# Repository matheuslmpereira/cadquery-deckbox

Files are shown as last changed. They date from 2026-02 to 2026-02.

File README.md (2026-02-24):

# cadquery-deckbox

## Environment

- Python: `3.11.14` (required for this setup)
- CadQuery: `2.6.1`
- OCP Viewer package: `ocp_vscode 3.0.1`
- Virtualenv interpreter:
  - `/Users/matheuslmpereira/Workspace/cadquery-deckbox/.venv/bin/python`

## Setup

```bash
cd /Users/matheuslmpereira/Workspace/cadquery-deckbox
/opt/homebrew/bin/python3.11 -m venv .venv
source .venv/bin/activate
pip install -r requirements.txt
```

## Run

```bash
source .venv/bin/activate
python build_box.py
python build_box.py --model commander_100
python build_box.py --model constructed_60_15
python build_box.py --model uno_36
python build_box.py --model color_addicted_40
python build_box.py --model commander_100 --no-viewer-output
```

- Sem `--model`, o script abre um seletor interativo no terminal.
- Por padrao, o script exporta um arquivo `.step` da montagem para CAD viewer.

## Verify environment

```bash
which python
python --version
python -m pip show cadquery ocp_vscode | rg "^Name:|^Version:"
```

Expected:

- `which python` -> `/Users/matheuslmpereira/Workspace/cadquery-deckbox/.venv/bin/python`
- `python --version` -> `Python 3.11.14`

## Notes

- Running with `/opt/homebrew/bin/python3 build_box.py` without activating `.venv` will fail with `ModuleNotFoundError: cadquery`.
- STL files are exported with model slug + version in the filename.
- In VSCode, select interpreter:
  - `Python: Select Interpreter` -> `/Users/matheuslmpereira/Workspace/cadquery-deckbox/.venv/bin/python`

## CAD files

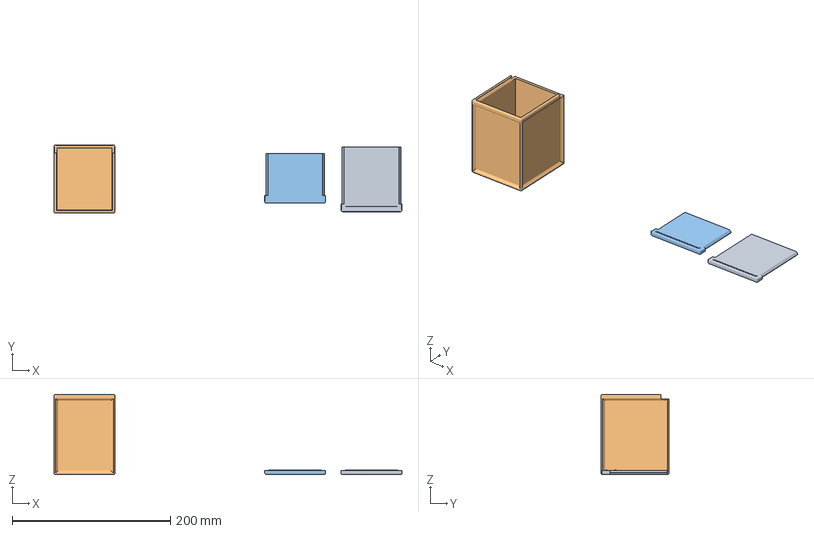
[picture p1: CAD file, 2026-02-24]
commander_deck_box_rainbow.3mf
439.7 x 86.0 x 101.3 mm
commander_deck_box_commander_100_lid_hex_v3.1.5.stl
commander_deck_box_commander_100_body_v3.1.5.stl
commander_deck_box_constructed_60_15_lid_hex_v3.1.5.stl

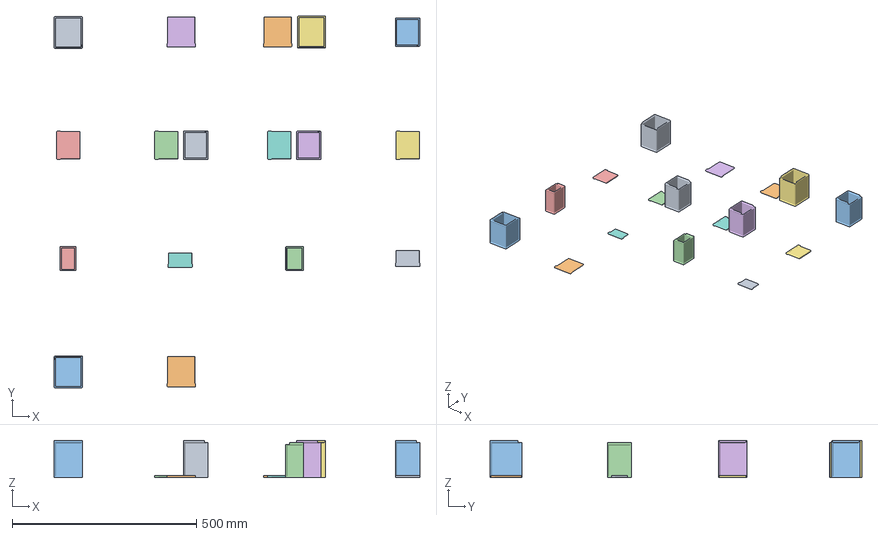
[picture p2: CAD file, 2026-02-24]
commander_deck_box_body_v3.0.10_valt.3mf
992.7 x 1007.9 x 101.3 mm
commander_deck_box_body_v3.0.8.stl x 2
commander_deck_box_commander_100_lid_hex_v3.1.5.stl
commander_deck_box_commander_100_body_v3.1.5.stl
commander_deck_box_color_addicted_40_body_v3.1.5.stl
commander_deck_box_uno_36_body_v3.1.5.stl
commander_deck_box_constructed_60_15_body_v3.1.1.stl x 3
commander_deck_box_constructed_60_15_lid_hex_v3.1.2.stl x 2
commander_deck_box_lid_hex_v3.0.10.stl x 2
commander_deck_box_constructed_60_15_lid_hex_v3.1.1.stl x 2
commander_deck_box_uno_36_lid_hex_v3.1.5.stl
commander_deck_box_color_addicted_40_lid_hex_v3.1.5.stl

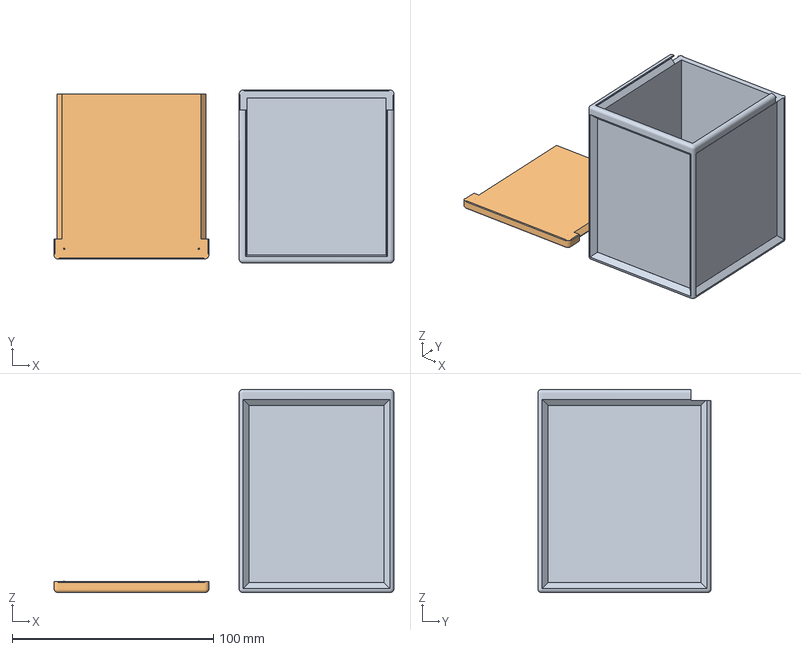
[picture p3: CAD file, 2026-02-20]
commander_deck_box_body_v3.0.6.3mf
169.0 x 86.0 x 101.1 mm
commander_deck_box_body_v3.0.6.stl
commander_deck_box_lid_hex_v3.0.6.stl

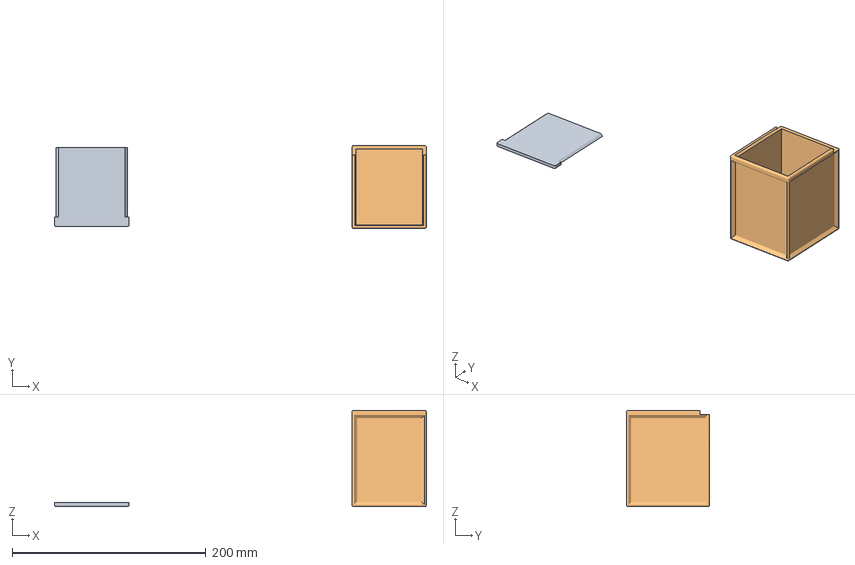
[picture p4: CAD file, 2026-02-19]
commander_deck_box_body_v3.0.5_gastadeira.3mf
384.2 x 86.0 x 99.6 mm
commander_deck_box_lid_hex_v3.0.5.stl
commander_deck_box_body_v3.0.5.stl

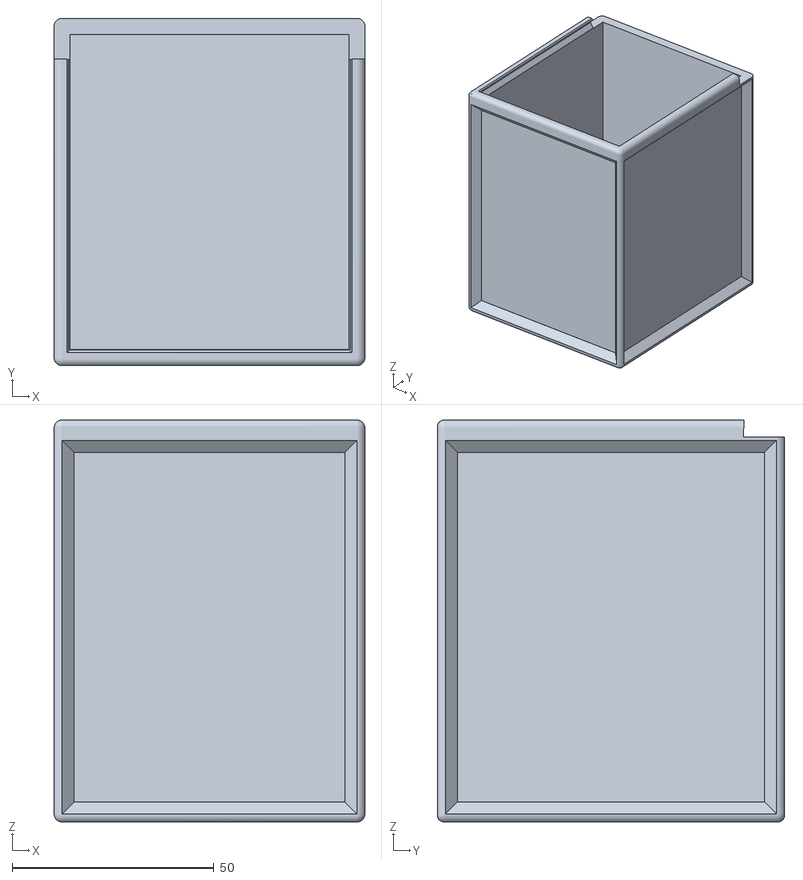
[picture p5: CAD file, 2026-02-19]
commander_deck_box_body_v3.0.0.stl
77.0 x 86.0 x 99.6

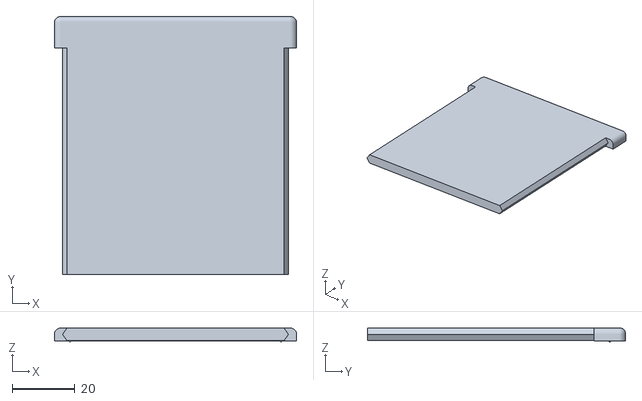
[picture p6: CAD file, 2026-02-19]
commander_deck_box_lid_hex_v3.0.0.stl
77.0 x 82.0 x 4.41

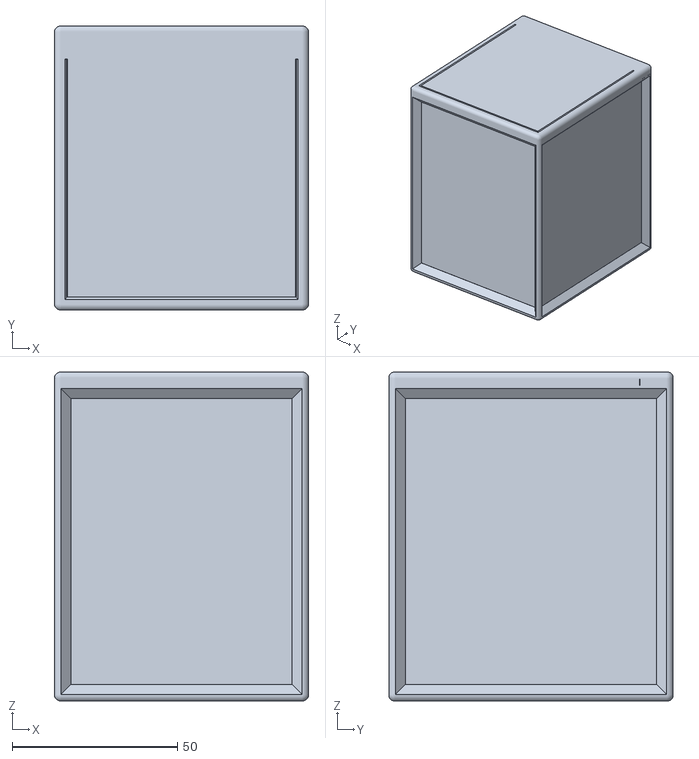
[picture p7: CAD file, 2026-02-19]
commander_deck_box_hex_v3.0.0.stl
77.0 x 86.0 x 99.6

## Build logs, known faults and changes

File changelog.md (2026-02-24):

# Model Changelog

- `v3.1.5`: Ajusta perfis UNO (`uno_36` e `color_addicted_40`) para fit de largura/altura com folga total de 2 mm.
- `v3.1.4`: Adiciona novos perfis de caixa com formato de carta UNO: `uno_36` (36 mm de profundidade interna) e `color_addicted_40` (40 mm de profundidade interna).
- `v3.1.3`: Adiciona no `build_box.py` export opcional de arquivo STEP da montagem para visualizacao em CAD viewer.
- `v3.1.2`: Adiciona segundo nivel na trava retangular de fechamento, com margem de 0.5 mm em relacao ao primeiro retangulo.
- `v3.1.1`: Adiciona seletor interativo de modelo no `build_box.py` quando `--model` nao e informado (escolha por numero ou slug no terminal).
- `v3.1.0`: Refatora execucao para `build_box.py` com selecao de perfil de caixa (`commander_100` e `constructed_60_15`), separa `main` da modelagem, e passa a incluir o slug do modelo no nome dos STLs exportados.
- `v3.0.10`: Desloca a trava retangular de fechamento em -1.0 mm no eixo Y.
- `v3.0.9`: Aumenta a altura da trava retangular de fechamento da tampa para 0.3 mm.
- `v3.0.8`: Substitui bolinhas de fechamento por trava retangular na tampa (profundidade 3.0 mm, altura 0.2 mm), mantendo as extremidades alinhadas com as posicoes laterais anteriores das bolinhas.
- `v3.0.7`: Aumenta a espessura do fundo da caixa para 0.84 mm (0.28 x 3 camadas).
- `v3.0.6`: Refina encaixe e manutencao: centraliza relief em `fit_relief_mm`, corrige alivio do sulco para eixos X/Z, adiciona crop do insert frontal no eixo Z, isola fusao em `fuseShapes` e alinha fluxo final para assembly sem recorte extra do corpo.
- `v3.0.5`: Ajustes de organização de projeto e minor fixis para a tampa
- `v3.0.4`: Aumenta lado do hexagono da tampa (hex_tip_offset_mm) para ampliar o corte de encaixe na caixa.
- `v3.0.3`: Remove groove_cut_depth_mm e sua logica; profundidade do sulco passa a depender apenas da geometria da tampa.
- `v3.0.2`: Remove duplicidade no corte do sulco; groove_cut_depth_mm agora estende a base do cutter de forma continua.
- `v3.0.1`: Aumenta um pouco a profundidade do sulco da tampa e passa a aplicar groove_cut_depth_mm no corte.
- `v3.0.0`: Versao estavel e imprimivel validada em PETG.
- `v2.0.25`: Reduz tamanho dos detentes em 20%.
- `v2.0.24`: Move detentes da tampa para a face inferior usando modo z_inner.
- `v2.0.23`: Corrige z_outer/z_inner para aplicar detentes em faces Z reais da tampa (nao mais alias de Y).
- `v2.0.22`: Padroniza nomenclatura de detentes para face Z (z_outer/z_inner), mantendo compatibilidade com y_outer/y_inner.
- `v2.0.21`: Reposiciona detentes para face externa no eixo horizontal (modo y_outer).
- `v2.0.20`: Restringe detentes ao modo x_inner para evitar aplicacao nas faces externas verticais da tampa.
- `v2.0.19`: Corrige orientacao dos detentes por normal de face (inner/outer) para aplicacao no lado correto.
- `v2.0.18`: Adiciona seletor de face dos detentes para teste rapido de posicionamento (x/y interno/externo).
- `v2.0.17`: Desfaz ordem do boolean no corpo inicial da tampa e retoma fluxo anterior com aplicacao de detentes.
- `v2.0.16`: Aplica boolean do insert frontal no corpo inicial da tampa (antes de arredondamentos e detentes).
- `v2.0.15`: Adiciona deslocamento de preview da tampa (explode) para melhor visualizacao no OCP CAD viewer.
- `v2.0.14`: Posiciona detentes na face interna da tampa (voltada para dentro da caixa).
- `v2.0.13`: Reposiciona detentes para a face externa da tampa e adiciona seletor explicito de face.
- `v2.0.12`: Adiciona 2 detentes na tampa para controle de fechamento, com corte correspondente em 80% no corpo.
- `v2.0.11`: Aumenta chanfro da depressao para referencia diagonal (hipotenusa) e reduz remanescente de angulo reto.
- `v2.0.10`: Define chanfro da depressao igual a profundidade (3.0 mm) para eliminar ombro de 90 graus.
- `v2.0.9`: Aumenta novamente o chanfro da depressao lateral para eliminar remanescente de angulo reto.
- `v2.0.8`: Aumenta o chanfro da depressao lateral para remover angulos retos na face da parede.
- `v2.0.7`: Aumenta hex_tip_offset_mm para ajustar a inclinacao do hexagono do trilho no sentido correto.
- `v2.0.6`: Reverte taper do sulco e aumenta o angulo do hexagono do trilho da tampa pelo perfil.
- `v2.0.5`: Aumenta a angulacao do sulco da tampa com taper: entrada mais folgada e fundo mais justo para maior pressao vertical.
- `v2.0.4`: Ajusta profundidade da depressao para manter 1 mm de parede principal com espessura externa de 4 mm.
- `v2.0.3`: Reforca paredes para carga na tampa, aprofunda depressao mantendo alma de 1 mm e amplia bordas do painel.
- `v2.0.2`: Corrige STL da tampa para slicer com boolean anti-coplanar no insert frontal.
- `v2.0.1`: Reduz espessura da base interna para 0.56 mm (2 camadas de 0.28 mm) visando impressao sem suporte.
- `v2.0.0`: Baseline estavel: paredes minimas viaveis, acabamento refinado e encaixe funcional.
- `v1.0.12`: Aplica arredondamento apenas na face frontal da tampa, usando o mesmo raio externo da caixa.
- `v1.0.11`: Corrige tampa vazada: rebaixo da tampa passa a usar apenas a intersecao com o insert frontal.
- `v1.0.10`: Nova abordagem para shape frontal da tampa: corta com o mesmo cutter da caixa e depois aplica o insert.
- `v1.0.9`: Evita sobreposicao ao inserir o shape frontal na tampa: abre rebaixo na intersecao antes da mescla.
- `v1.0.8`: Mescla na tampa o volume removido da entrada frontal da caixa (complemento real do shape).
- `v1.0.7`: Aplica o mesmo shape da entrada frontal da caixa na tampa para continuidade visual.
- `v1.0.6`: Reduz folga de encaixe da tampa para ajuste mais justo com atrito (FDM).
- `v1.0.5`: Arredonda arestas externas da caixa (verticais e base) para reduzir impacto de quina.
- `v1.0.4`: Vincula a altura do corte frontal a altura da tampa para manter proporcao apos redimensionar paredes.
- `v1.0.3`: Compensa a intrusao da tampa aumentando a altura interna util da caixa em 1x a altura da tampa.
- `v1.0.2`: Adiciona depressao de 1.0 mm nas quatro faces laterais externas da caixa.
- `v1.0.1`: Interno sem arredondamento e trilho com respiro extra para encaixe FDM mais folgado.
- `v1.0.0`: Baseline estavel e funcional aprovado para caixa + tampa hex com corte negativo alinhado.
- `v0.9.4`: Simplifica para cutter unico alinhado (remove corte duplo e evita falha booleana).
- `v0.9.3`: Remove degrau duplo no sulco: cutter unico com extensao continua para baixo.
- `v0.9.2`: Corrige artefatos no canto: chamfer aplicado somente no aro interno e corte negativo com folga Z anti-coplanar.
- `v0.9.1`: Corte negativo alinhado com a posicao final da tampa; profundidade adicional aplicada apenas para baixo.
- `v0.9.0`: Aplica corte negativo da tampa na caixa com profundidade de sulco controlada.
- `v0.8.2`: Corrige posicionamento Y da tampa para o path explicito: de parede interna traseira ate parede externa frontal.
- `v0.8.1`: Inverte orientacao da tampa no eixo Y (frente/tras) sem alterar o alcance do path.
- `v0.8.0`: Altura da tampa igual a espessura da parede; path em Y da parede externa frontal ate parede interna traseira.
- `v0.7.1`: Centraliza automaticamente a tampa no eixo X/Y pelo bounding box antes do corte.
- `v0.7.0`: Face superior da tampa hex igual a largura interna da caixa e tampa mantida centralizada tampando a caixa.
- `v0.6.0`: Corrige profundidade da tampa hex (extrude one-side + recenter Y) e mantem corte com tampa montada.
- `v0.5.0`: Corte da caixa usando a propria tampa hex e separacao da tampa no preview.
- `v0.4.0`: Tampa hex com largura caixa-2mm e ombro de 1mm.

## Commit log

2026-02-19 stl v3
    [commander_deck_box_body_v3.0.0.stl, commander_deck_box_hex_v3.0.0.stl, commander_deck_box_lid_hex_v3.0.0.stl]
2026-02-19 melhorias para abrir a tampa
    [commander_deck_box_body_v3.0.5_gastadeira.3mf, commander_deck_box_body_v3.0.6.3mf]
2026-02-20 aumento do fundo da caixa
    [commander_deck_box_body_v3.0.6.3mf]
2026-02-20 Substitui bolinhas de fechamento por trava retangular
2026-02-24 ultima versão
    [commander_deck_box_body_v3.0.10_valt.3mf, commander_deck_box_rainbow.3mf]
